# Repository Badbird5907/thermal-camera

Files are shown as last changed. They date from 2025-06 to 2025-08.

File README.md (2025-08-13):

# Thermal Camera
[Video Demo](https://www.youtube.com/shorts/hk5CXilCE_w)

**This project was posted to [Hackaday](https://hackaday.com/2025/08/10/cheap-thermal-camera-fits-the-bill/)!**

This is my design of a cheap and affordable thermal camera (< $60, excl shipping)!. It utilizes the MLX90640 as the image sensor, and the esp32 to process and display the images on a TFT LCD screen.

I made this project because off the shelf thermal cameras are exuberantly expensive, and I need one to figure out if my PCBs are shorting.

The hardest part of this project so far was designing the battery charging circuit, as I needed to use multiple ICs to charge the battery, keep the voltage stable, and to keep the battery from overcharging.

# Screenshots



ApplicationFrameHost_TMCDneAYK6

-> The case (and PCB) isn't very well designed, If I redesigned this project, i'd make the pcb smaller and integrate the LCD...

# Photos




# Firmware
You can find the firmware in the `thermal_camera` folder.

The firmware is written with the Arduino IDE. The ESP32 is used to read the thermal camera and display the images on the TFT LCD screen.

## Firmware Setup
1. Open the Arduino IDE.
2. Install the TFT_eSPI library and MLX90640 library by Adafruit.
3. Create a thermal_camera.h file in `C:\Users\YourUsername\Documents\Arduino\libraries\TFT_eSPI\User_Setups`
4. Paste in the following code:
```c
#define ILI9341_DRIVER
#define TFT_WIDTH 240 
#define TFT_HEIGHT 320 

#define TFT_MISO 8 
#define TFT_MOSI 6 
#define TFT_SCLK 5 
#define TFT_CS 15 
#define TFT_DC 4 
#define TFT_RST 16 
#define TFT_BL 7 

#define TOUCH_CS 10

#define SPI_FREQUENCY 40000000
```
5. Open `C:\Users\YourUsername\Documents\Arduino\libraries\TFT_eSPI\User_Setup_Select.h`
6. Add the line `#include <User_Setups/thermal_camera.h>` to the file under User_Setup.h
7. Compile and upload the firmware to the ESP32.

# BOM
The total cost of the project is about $86 USD: ([Spreadsheet](https://docs.google.com/spreadsheets/d/1PjPY5GV_mC4sFPF-p1Rz1wbnOWLJnwNhDzCwLhk1jFM/edit?usp=sharing))


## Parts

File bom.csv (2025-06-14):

Name | Qty | Price (CAD) |  | Total | Total (USD)
CAP CER 4.7UF 25V X5R 0805 | 10 | 0.83 |  | 158.41 | 116.5936775
CAP CER 10UF 10V X7R 0805 | 10 | 0.44
CAP CER 1UF 50V X7R 0805 | 10 | 0.35
CAP CER 0.1UF 100V X7R 0805 | 10 | 0.2
CAP CER 0.22UF 50V X7R 0805 | 10 | 0.28
PTC RESET FUSE 6V 1.5A 1206 | 1 | 0.7
RES 5.1K OHM 5% 1/8W 0805 | 10 | 0.12
RES 470 OHM 5% 1/8W 0805 | 10 | 0.48
RES 0 OHM JUMPER 1/8W 0805 | 10 | 0.16
RES SMD 10K OHM 5% 1/8W 0805 | 10 | 0.64
RES 4.02K OHM 1% 1/8W 0805 | 10 | 0.39
RES SMD 20K OHM 0.1% 1/8W 0805 | 10 | 0.95
RES SMD 2.2K OHM 1% 1/8W 0805 | 10 | 0.54
RES 1K OHM 1% 1/8W 0805 | 10 | 0.19
IC BATT CHG LI-ION 1CELL 20QFN | 1 | 3.74
IC REG LINEAR 3.3V 300MA SOT23-5 | 1 | 0.25
1.5V~10V LITHIUM-ION/POLYMER 1 S | 1 | 0.16
SENSOR DGTL -40C-85C TO39 | 1 | 54.76
SWITCH SLIDE DPDT 1A 125V | 1 | 2.78
THERMALLY STABLE SOLDER PASTE NO | 1 | 24.65
CONN HDR 14POS 0.1 TIN PCB | 1 | 1.13
10Pair 2P JST PH Connectors | 1 | 3.23
2.8" TFT | 1 | 9.78
ESP32 S3 WROOM-1 N16R8 | 1 | 4.63
Battery | 1 | 18.79
Digikey Shipping |  | 8
JLCPCB
PCB |  |  | 2
Stencil |  |  | 9.57
Shipping |  |  | 8.67
JLC TOTAL |  | 20.24 | 20.24

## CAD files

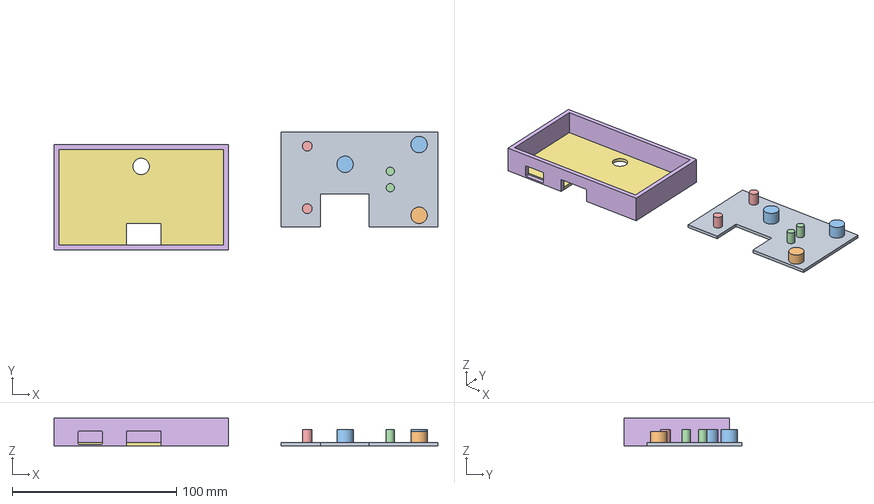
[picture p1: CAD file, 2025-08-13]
case.step
233.5 x 71.5 x 17.0 mm

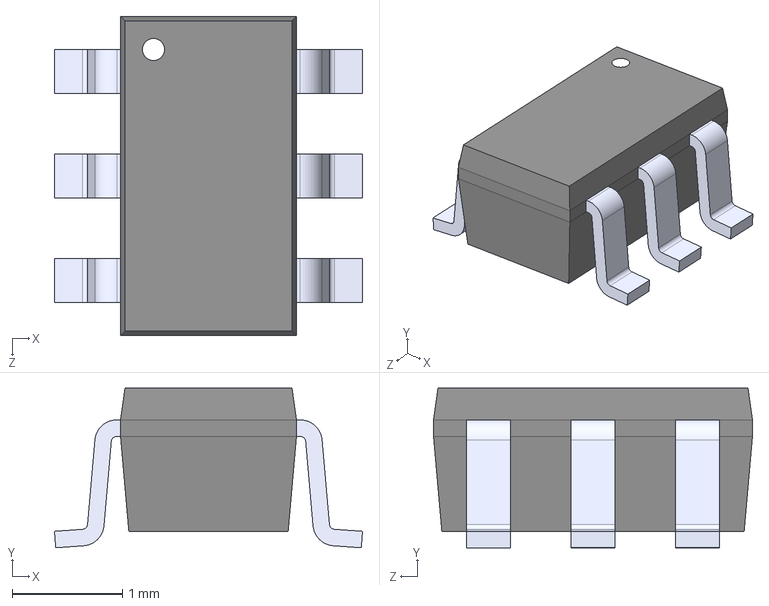
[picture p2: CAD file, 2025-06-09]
thermal-pcb/Component/FS8205.step
2.80 x 1.45 x 2.90 mm

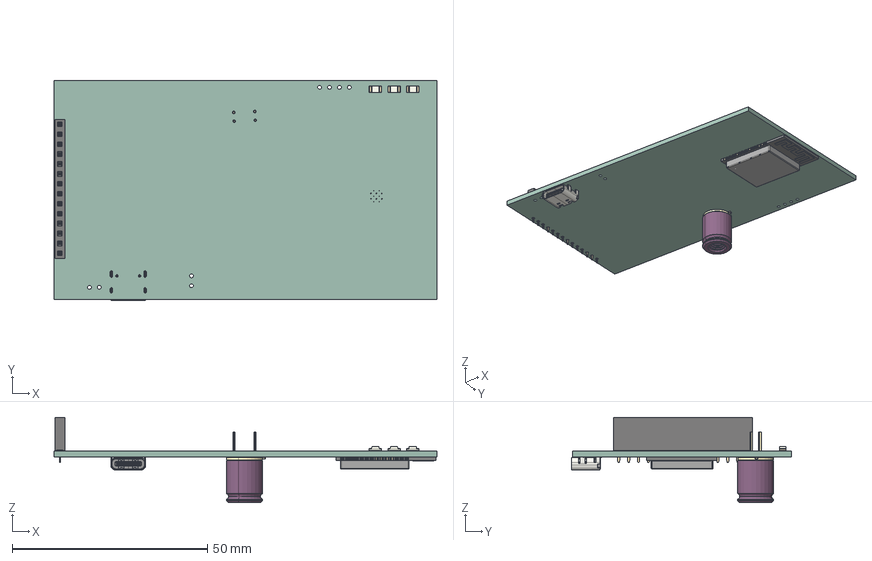
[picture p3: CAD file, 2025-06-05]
thermal-pcb/thermal-pcb.step
98.0 x 56.3 x 21.8 mm
LED_1206_3216Metric x 3
PinSocket_1x14_P2.54mm_Vertical
ESP32-S3-WROOM-1
MLX90640ESF-BAB-000-SP
USB_C_Receptacle_GCT_USB4105-xx-A_16P_TopMnt_Horizontal
thermal-pcb_PCB

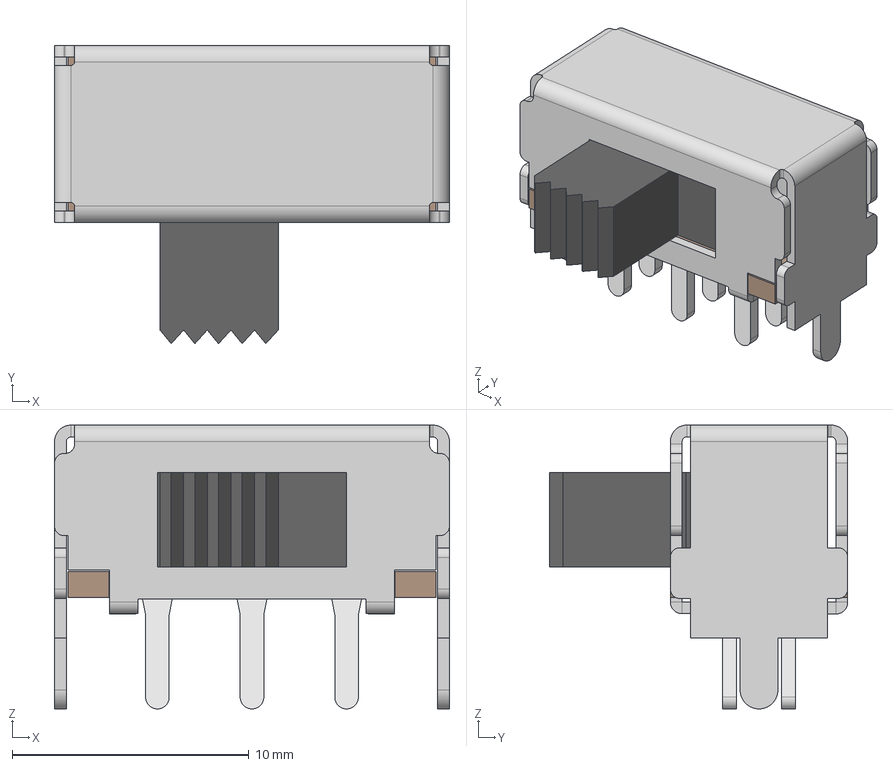
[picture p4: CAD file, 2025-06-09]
thermal-pcb/Component/MFS201N-19-Z.step
16.7 x 12.6 x 12.0 mm
BodyBottomPlate

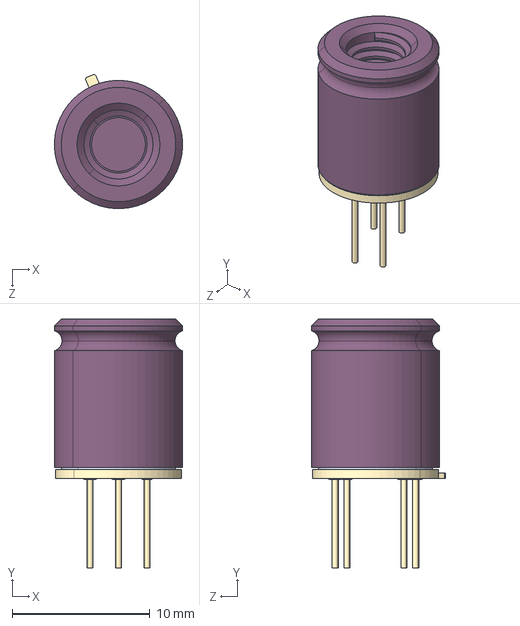
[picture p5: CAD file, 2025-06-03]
thermal-pcb/Component/MLX90640ESF-BAB-000-SP.step
9.28 x 18.1 x 9.72 mm

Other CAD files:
thermal-pcb/Component/MLX90640.sldprt

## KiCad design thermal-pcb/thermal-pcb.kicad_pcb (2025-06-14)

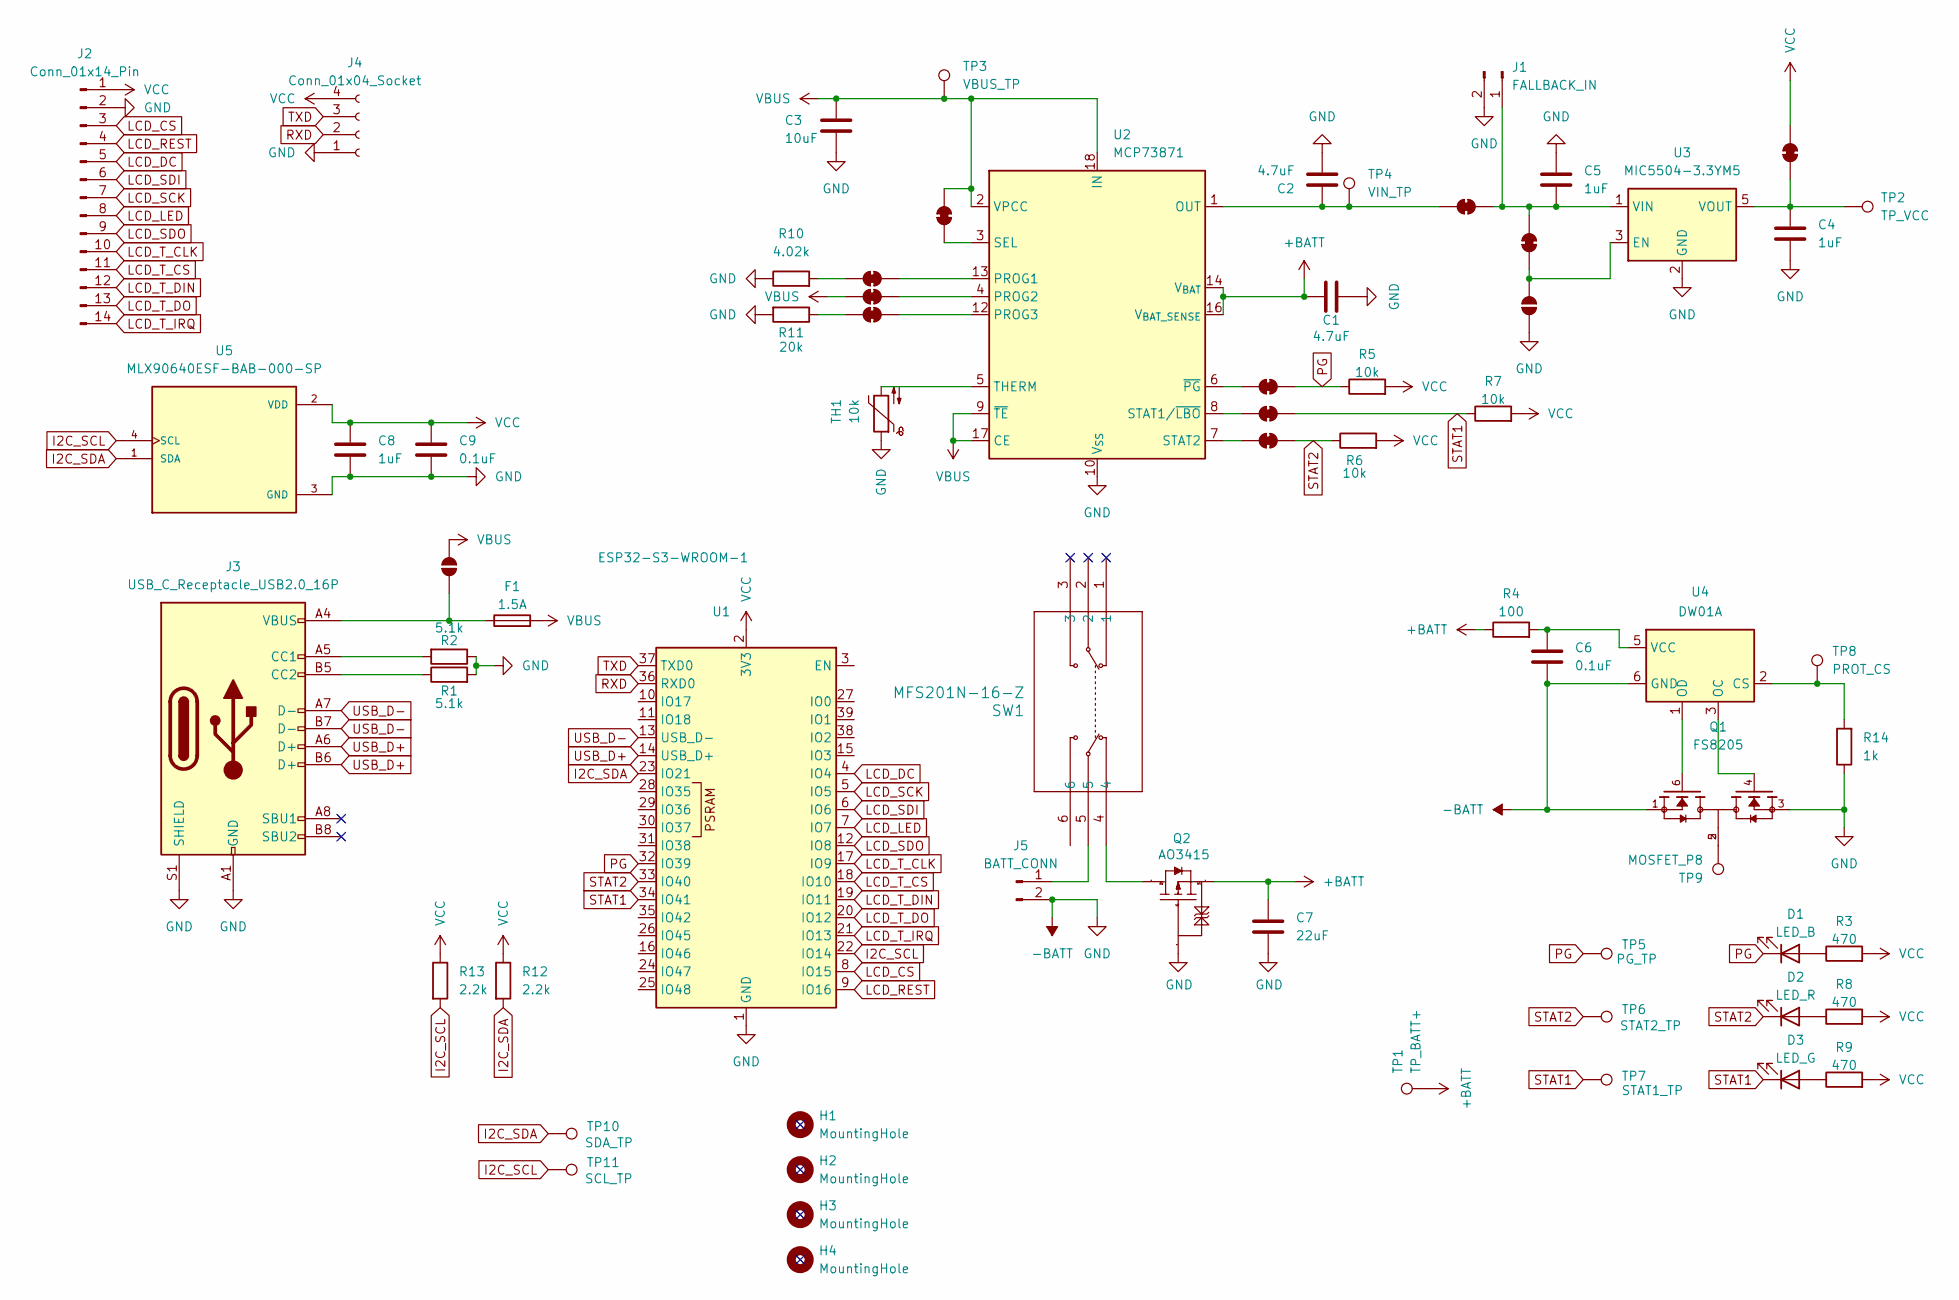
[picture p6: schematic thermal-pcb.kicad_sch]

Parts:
C1, C2: 4.7uF; C_0805_2012Metric
C3: 10uF; C_0805_2012Metric
C4, C5, C8: 1uF; C_0805_2012Metric
C6, C9: 0.1uF; C_0805_2012Metric
C7: 22uF; C_0805_2012Metric
D1: LED_B; LED_1206_3216Metric
D2: LED_R; LED_1206_3216Metric
D3: LED_G; LED_1206_3216Metric
F1: 1.5A; Fuse_1206_3216Metric
H1, H2, H3, H4: MountingHole; MountingHole_4.3mm_M4
J1: FALLBACK_IN; PinHeader_1x02_P2.54mm_Vertical
J2: Conn_01x14_Pin; PinSocket_1x14_P2.54mm_Vertical
J3: USB_C_Receptacle_USB2.0_16P; USB_C_Receptacle_GCT_USB4105-xx-A_16P_TopMnt_Horizontal
J4: Conn_01x04_Socket; PinSocket_1x04_P2.54mm_Vertical
J5: BATT_CONN; PinSocket_1x02_P2.54mm_Vertical
JP1: EN_VCC; SolderJumper-2_P1.3mm_Bridged_RoundedPad1.0x1.5mm
JP2: EN_GND; SolderJumper-2_P1.3mm_Open_RoundedPad1.0x1.5mm
JP3: PROG1_JP; SolderJumper-2_P1.3mm_Bridged_RoundedPad1.0x1.5mm
JP4: PROG2_JP; SolderJumper-2_P1.3mm_Bridged_RoundedPad1.0x1.5mm
JP5: PROG3_JP; SolderJumper-2_P1.3mm_Bridged_RoundedPad1.0x1.5mm
JP6: SEL_JP; SolderJumper-2_P1.3mm_Bridged_RoundedPad1.0x1.5mm
JP7: PG_JP; SolderJumper-2_P1.3mm_Bridged_RoundedPad1.0x1.5mm
JP8: STAT1_JP; SolderJumper-2_P1.3mm_Bridged_RoundedPad1.0x1.5mm
JP9: STAT2_JP; SolderJumper-2_P1.3mm_Bridged_RoundedPad1.0x1.5mm
JP10: VCC_JP; SolderJumper-2_P1.3mm_Bridged_RoundedPad1.0x1.5mm
JP11: BMS_VOUT; SolderJumper-2_P1.3mm_Bridged_RoundedPad1.0x1.5mm
JP12: FUSE_BYPASS; SolderJumper-2_P1.3mm_Open_RoundedPad1.0x1.5mm
Q1: FS8205; SOT95P280X145-6N; PARTREV 1.9
Q2: AO3415; SOT-23-3_L2.9-W1.3-P1.90-LS2.4-BR; Manufacturer Part AO3415; LCSC Part Name 1个P沟道 耐压:20V 电流:4A
R1, R2: 5.1k; R_0805_2012Metric
R3, R8, R9: 470; R_0805_2012Metric
R4: 100; R_0805_2012Metric
R5, R6, R7: 10k; R_0805_2012Metric
R10: 4.02k; R_0805_2012Metric
R11: 20k; R_0805_2012Metric
R12, R13: 2.2k; R_0805_2012Metric
R14: 1k; R_0805_2012Metric
SW1: MFS201N-16-Z; MFS201N-16-Z_NDC
TH1: 10k; R_0805_2012Metric
TP1: TP_BATT+; TestPoint_Pad_D1.5mm
TP2: TP_VCC; TestPoint_Pad_D1.5mm
TP3: VBUS_TP; TestPoint_Pad_D1.5mm
TP4: VIN_TP; TestPoint_Pad_D1.5mm
TP5: PG_TP; TestPoint_Pad_D1.5mm
TP6: STAT2_TP; TestPoint_Pad_D1.5mm
TP7: STAT1_TP; TestPoint_Pad_D1.5mm
TP8: PROT_CS; TestPoint_Pad_D1.5mm
TP9: MOSFET_P8; TestPoint_Pad_D1.5mm
TP10: SDA_TP; TestPoint_Pad_D1.5mm
TP11: SCL_TP; TestPoint_Pad_D1.5mm
U1: ESP32-S3-WROOM-1
U2: MCP73871; QFN-20-1EP_4x4mm_P0.5mm_EP2.5x2.5mm
U3: MIC5504-3.3YM5; SOT-23-5
U4: DW01A; SOT-23-6
U5: MLX90640ESF-BAB-000-SP; TO292P945H1165-4; PARTREV 11

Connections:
+BATT: C1.1, C7.1, Q2.2 (S), R4.1, TP1.1, U2.14 (V_{BAT}), U2.15 (V_{BAT}), U2.16 (V_{BAT_SENSE})
-BATT: C1.2, C2.2, C3.2, C4.2, C5.1, C6.2, C7.2, C8.2, C9.2, J1.2, J2.2, J3.A1 (GND), J3.A12 (GND), J3.B1 (GND), J3.B12 (GND), J3.S1 (SHIELD), J4.1, J5.2, JP2.1 (A), Q1.1, Q1.3, Q2.1 (G), R1.2, R2.1, R10.1, R11.2, R14.1, TH1.1, U1.1 (GND), U1.40 (GND), U1.41 (GND), U2.10 (V_{SS}), U2.11 (V_{SS}), U2.21 (V_{SS}), U3.2 (GND), U4.6 (GND), U5.3 (GND)
I2C_SCL: R13.2, TP11.1, U1.22 (IO14), U5.4 (SCL)
I2C_SDA: R12.2, TP10.1, U1.23 (IO21), U5.1 (SDA)
LCD_CS: J2.3, U1.8 (IO15)
LCD_DC: J2.5, U1.4 (IO4)
LCD_LED: J2.8, U1.7 (IO7)
LCD_REST: J2.4, U1.9 (IO16)
LCD_SCK: J2.7, U1.5 (IO5)
LCD_SDI: J2.6, U1.6 (IO6)
LCD_SDO: J2.9, U1.12 (IO8)
LCD_T_CLK: J2.10, U1.17 (IO9)
LCD_T_CS: J2.11, U1.18 (IO10)
LCD_T_DIN: J2.12, U1.19 (IO11)
LCD_T_DO: J2.13, U1.20 (IO12)
LCD_T_IRQ: J2.14, U1.21 (IO13)
unnamed: D1.2 (A), R3.1
unnamed: D2.2 (A), R8.1
unnamed: D3.2 (A), R9.1
unnamed: C5.2, J1.1, JP1.1 (A), JP11.1 (A), U3.1 (VIN)
unnamed: J3.A5 (CC1), R2.2
unnamed: J3.B5 (CC2), R1.1
unnamed: J5.1, SW1.5
unnamed: JP1.2 (B), JP2.2 (B), U3.3 (EN)
unnamed: JP3.1 (A), R10.2
unnamed: JP3.2 (B), U2.13 (PROG1)
unnamed: JP4.1 (A), U2.4 (PROG2)
unnamed: JP5.1 (A), U2.12 (PROG3)
unnamed: JP5.2 (B), R11.1
unnamed: JP6.1 (A), U2.3 (SEL)
unnamed: JP7.1 (A), U2.6 (~PG)
unnamed: JP8.1 (A), U2.8 (STAT1/~LBO)
unnamed: JP9.1 (A), U2.7 (STAT2)
unnamed: C4.1, JP10.2 (B), TP2.1, U3.5 (VOUT)
unnamed: C2.1, JP11.2 (B), TP4.1, U2.1 (OUT), U2.20 (OUT)
unnamed: F1.1, J3.A4 (VBUS), J3.A9 (VBUS), J3.B4 (VBUS), J3.B9 (VBUS), JP12.1 (A)
unnamed: Q1.2, Q1.5, TP9.1
unnamed: Q2.3 (D), SW1.4
unnamed: TH1.2, U2.5 (THERM)
unnamed: R14.2, TP8.1, U4.2 (CS)
unnamed: Q1.4, U4.3 (OC)
unnamed: Q1.6, U4.1 (OD)
unnamed: C6.1, R4.2, U4.5 (VCC)
PG: D1.1 (K), JP7.2 (B), R5.1, TP5.1, U1.32 (IO39)
RXD: J4.2, U1.36 (RXD0)
STAT1: D3.1 (K), JP8.2 (B), R7.1, TP7.1, U1.34 (IO41)
STAT2: D2.1 (K), JP9.2 (B), R6.1, TP6.1, U1.33 (IO40)
TXD: J4.3, U1.37 (TXD0)
USB_D+: J3.A6 (D+), J3.B6 (D+), U1.14 (USB_D+)
USB_D-: J3.A7 (D-), J3.B7 (D-), U1.13 (USB_D-)
VBUS: C3.1, F1.2, JP4.2 (B), JP6.2 (B), JP12.2 (B), TP3.1, U2.2 (VPCC), U2.9 (~TE), U2.17 (CE), U2.18 (IN), U2.19 (IN)
VCC: C8.1, C9.1, J2.1, J4.4, JP10.1 (A), R3.2, R5.2, R6.2, R7.2, R8.2, R9.2, R12.1, R13.1, U1.2 (3V3), U5.2 (VDD)

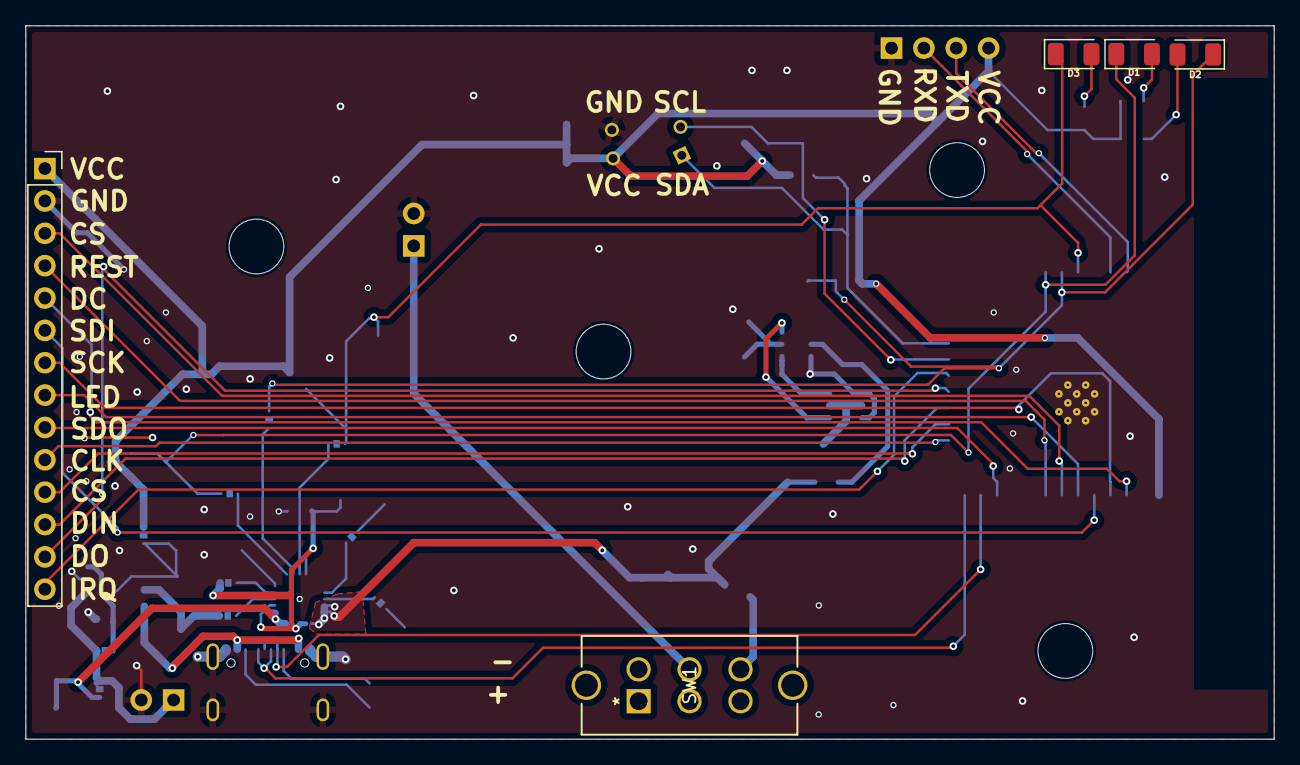
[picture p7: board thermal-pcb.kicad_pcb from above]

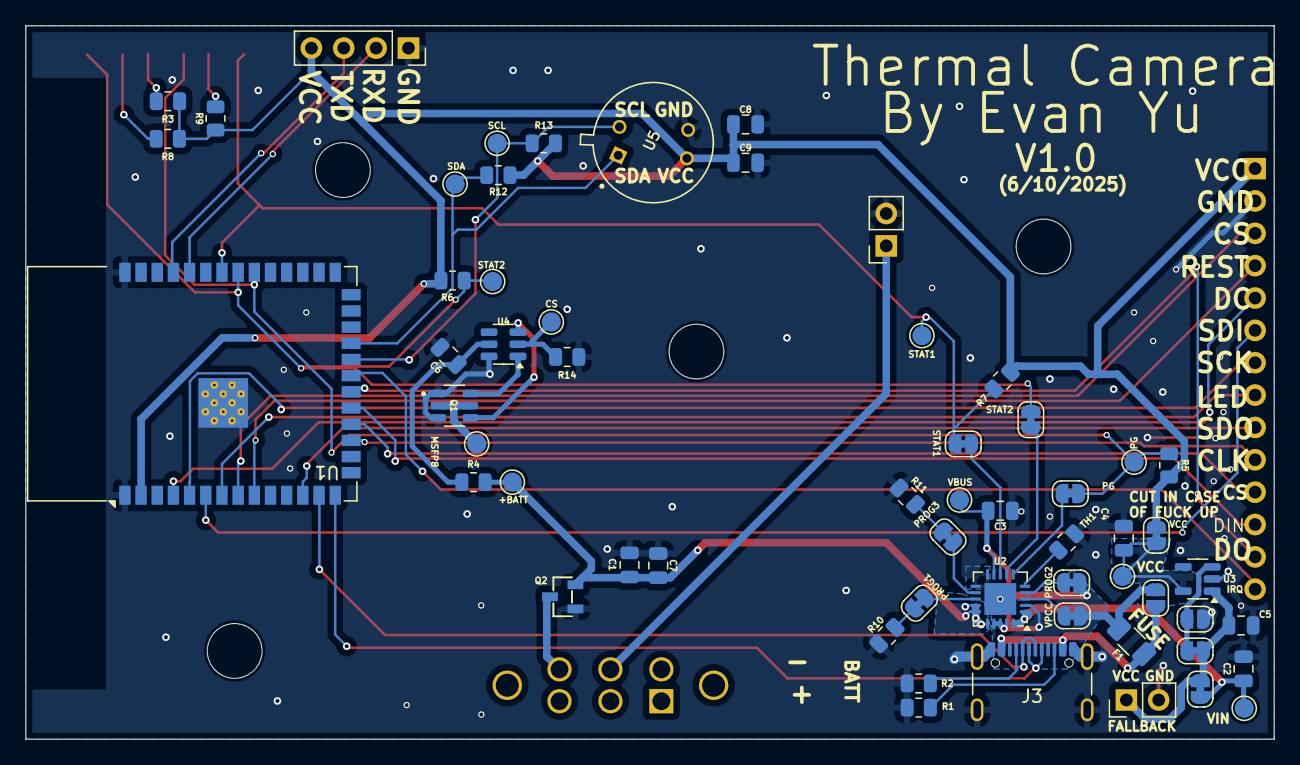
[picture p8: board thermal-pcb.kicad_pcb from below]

Board: 2 copper layers, 98.0 x 56.0 mm, 68 parts (59 on the bottom side), 52 nets.

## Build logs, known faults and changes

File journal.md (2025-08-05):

**Total Time: 34h**

# 5/26
Time spent: 2h
Researched different types of thermal cameras. I finally landed on the [Adafruit MLX90640 IR Thermal Camera Breakout](https://www.adafruit.com/product/4407).
I mainly chose this breakout because:
1. It came from a reputable manufacturer
2. It looked like it had decent quality
3. It communicates over i2c, making it really easy to work with.

For the screen, I decided on a generic 2.8" TFT LCD screen.
I also chose a ESP32-S3-WROOM-1 as the main MCU for this project.

# 5/28
Time spent: 4h
I found [this](https://www.reddit.com/r/electronics/comments/a70koi/comment/ebzriyd/) lipo charger circuit on reddit. Since it outputs 5V
--
Spent quite a few hours looking up different lipo charger/discharge circuits. I've landed on charging a 18650 or similar battery using a MCP73871 and a MIC5504. Then spent a lot of time designing the schematic

# 5/29 & 5/30
Time spent: 5h

I spent a lot of time investigating different IR sensor modules. I finally landed on the MLX90640, which is a cheap thermal sensor with a resolution of 32x24 pixels. I then spent a lot of time designing the schematic.
I'm also looking into turning this into a module that plugs into an android phone.

# 5/31
Time spent: 3h

Finalized schematic design and started work on PCB routing. I might attempt to rip out everything battery charging related and reimplement it

# 6/1
Time spent: 3h

Spent a lot of time routing the pcb

# 6/2
Time spent: 5h
Routing pcb and fixing issues with schematic.

# 6/3
Time spent: 2h
Finializing pcb, added fallback pins to the power in

# 6/4
Time spent: 5h
Finished the PCB, sourced parts. Finished the case CAD.
ApplicationFrameHost_UEK0gMYSmj
ApplicationFrameHost_Y9mpmJQMrD
ApplicationFrameHost_TMCDneAYK6
kicad_72Akr1wMqy
kicad_yXDkx9Mt58
kicad_kI7ghjKoyS

# 6/11 - 6/13
Time spent: 2h
Reworked bom to use some parts from aliexpress. Also reworked some traces on the PCB and moved the battery connector to the top left. I've also added and remove parts from the digikey bom that I forgot.

# 7/8

Time spent: 5h

Parts arrived, I reflowed all the parts on the board, and spent forever debugging both software and hardware. Ended up having to bodge wire some pins, but it works!
I also had to go into the Arduino TFT library to get it to work with my ESP32.





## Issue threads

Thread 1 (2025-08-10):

Add license information

vazhnov, 2025-08-10:
Hello!

I found this amazing project from https://hackaday.com/2025/08/10/cheap-thermal-camera-fits-the-bill/

Could you please add information about the license of this repository — is it allowed to copy, change and use the code, documentation and PCB hardware files in any purpose?
It would be great to see any popular open source license.

vazhnov, 2025-08-13:
The  MIT license — amazing! Thank you!

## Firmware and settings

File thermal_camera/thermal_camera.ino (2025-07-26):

#include <Wire.h>
#include <Adafruit_MLX90640.h>
#include <SPI.h>
#include <TFT_eSPI.h>

#define LCD_LED_PIN 7
#define I2C_SCL_PIN 14
#define I2C_SDA_PIN 21

Adafruit_MLX90640 mlx;
float frame[32 * 24]; // 32x24 pixels

TFT_eSPI tft = TFT_eSPI(); // init display

uint16_t colormap[256]; // color palette temp -> color

bool autoScale = true;
float fixedMin = 20.0;
float fixedMax = 35.0;

void setup() {
  Serial.begin(9600);

  // init I2C
  Wire.begin(I2C_SDA_PIN, I2C_SCL_PIN);
  Wire.setClock(400000); // 400kHz

  // init thermal camera
  if (!mlx.begin(MLX90640_I2CADDR_DEFAULT, &Wire)) {
    Serial.println("No MLX90640 found!");
    while (1) delay(10);
  }

  mlx.setRefreshRate(MLX90640_4_HZ);

  // init TFT display
  tft.init();
  tft.setRotation(2); // Rotate 180 degrees to fix upside-down image
  tft.fillScreen(TFT_BLACK);

  // set backlight
  pinMode(LCD_LED_PIN, OUTPUT);
  digitalWrite(LCD_LED_PIN, HIGH);

  generateColormap();
}

void loop() {
  if (mlx.getFrame(frame) != 0) { // read frame
    Serial.println("No frame data");
    delay(500);
    return;
  }

  // find min and max temperatures for auto-scaling
  float minTemp = 100;
  float maxTemp = 0;

  if (autoScale) {
    for (int i = 0; i < 32 * 24; i++) {
      if (frame[i] > 0 && frame[i] < 100) { // filter invalid readings
        minTemp = min(minTemp, frame[i]);
        maxTemp = max(maxTemp, frame[i]);
      }
    }

    // prevent too narrow temperature range
    if (maxTemp - minTemp < 5.0) {
      float midTemp = (maxTemp + minTemp) / 2;
      minTemp = midTemp - 2.5;
      maxTemp = midTemp + 2.5;
    }
  } else {
    // use fixed range
    minTemp = fixedMin;
    maxTemp = fixedMax;
  }

  displayThermalImage(minTemp, maxTemp);

  tft.setTextColor(TFT_WHITE, TFT_BLACK); // show min and max temperatures
  tft.setTextSize(2);
  tft.setCursor(10, 10);
  tft.print("Min: ");
  tft.print(minTemp, 1);
  tft.print("C");

  tft.setCursor(10, 40);
  tft.print("Max: ");
  tft.print(maxTemp, 1);
  tft.print("C");

  delay(250);
}

void generateColormap() { // generate color palette
  for (int i = 0; i < 256; i++) {
    if (i < 64) {
      colormap[i] = tft.color565(0, 0, i * 4); // black to blue
    } else if (i < 128) {
      colormap[i] = tft.color565(0, (i - 64) * 4, 255); // blue to cyan
    } else if (i < 192) {
      colormap[i] = tft.color565((i - 128) * 4, 255, 255 - (i - 128) * 4); // cyan to yellow
    } else {
      colormap[i] = tft.color565(255, 255 - (i - 192) * 4, 0); // yellow to red
    }
  }
}

void displayThermalImage(float minTemp, float maxTemp) { // display thermal image on TFT
  // calculate display size and scaling
  int displayWidth = tft.width();
  int displayHeight = tft.height();

  // scale pixel to display size
  int pixelWidth = displayWidth / 32;
  int pixelHeight = (displayHeight - 100) / 24; // reserve space for text

  // center image
  int offsetX = (displayWidth - (32 * pixelWidth)) / 2;
  int offsetY = 70; // space at top for text

  // display each thermal pixel
  for (int y = 0; y < 24; y++) {
    for (int x = 0; x < 32; x++) {
      // Flip horizontally by reversing the x-coordinate
      int flippedX = 31 - x; // Flip the x-coordinate (32 pixels wide)

      float temp = frame[y * 32 + flippedX];

      // map temp to color index
      int colorIndex;
      if (temp < minTemp) colorIndex = 0;
      else if (temp > maxTemp) colorIndex = 255;
      else colorIndex = map(temp * 100, minTemp * 100, maxTemp * 100, 0, 255);

      tft.fillRect( // one pixel
        offsetX + x * pixelWidth, // Use the original x-coordinate for display
        offsetY + y * pixelHeight,
        pixelWidth,
        pixelHeight,
        colormap[colorIndex]
      );
    }
  }

  // scale bar
  int barHeight = 20;
  int barWidth = displayWidth - 40;
  int barX = 20;
  int barY = displayHeight - 30;

  for (int i = 0; i < barWidth; i++) {
    int colorIndex = map(i, 0, barWidth - 1, 0, 255);
    tft.drawFastVLine(barX + i, barY, barHeight, colormap[colorIndex]);
  }

  // color scale label
  tft.setTextColor(TFT_WHITE, TFT_BLACK);
  tft.setTextSize(1);
  tft.setCursor(barX, barY - 15);
  tft.print(minTemp, 1);
  tft.print("C");

  tft.setCursor(barX + barWidth - 40, barY - 15);
  tft.print(maxTemp, 1);
  tft.print("C");
}

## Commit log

2025-05-29 work on pcb
    [thermal-pcb.kicad_sch]
2025-05-30 work on schematic
    [thermal-pcb.kicad_pcb, thermal-pcb.kicad_sch]
2025-06-01 route most traces
    [thermal-pcb.kicad_pcb, thermal-pcb.kicad_sch]
2025-06-03 some stuff
    [MLX90640ESF-BAB-000-SP.step, thermal-pcb.kicad_pcb, thermal-pcb.kicad_sch]
2025-06-05 almost done pcb
    [thermal-pcb.kicad_pcb, thermal-pcb.kicad_sch]
2025-06-05 finish pcb
    [thermal-pcb-CuBottom.gbr, thermal-pcb-CuTop.gbr, thermal-pcb-EdgeCuts.gbr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]
2025-06-09 add firmware
    [FS8205.step, FS8205A.step, MFS201N-19-Z.step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]
2025-06-14 update pcb + bom to use aliexpress stuff
    [bom.csv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]
2025-06-14 use cheaper shipping for jlc
    [bom.csv]
2025-06-14 forgot some things
    [bom.csv]
2025-08-13 update case + readme
    [case.step]
